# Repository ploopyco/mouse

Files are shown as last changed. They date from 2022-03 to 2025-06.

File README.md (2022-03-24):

# The Ploopy Mouse

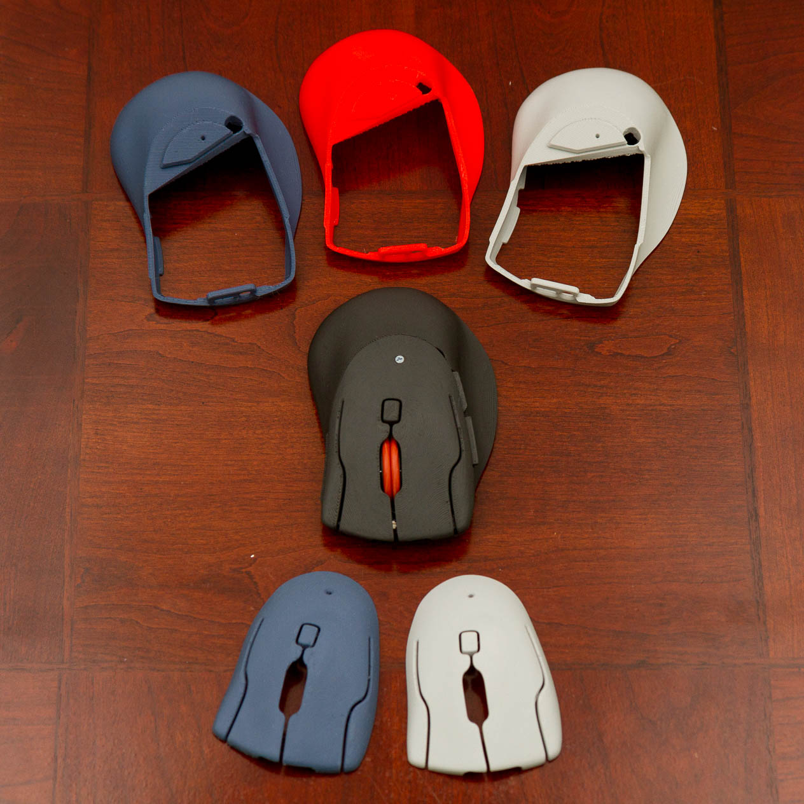
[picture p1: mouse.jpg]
The Ploopy Mouse


By some stroke of luck, you've made your way here. The Ploopy Mouse. Your life will never be the same.

This repository contains all of the design and production files necessary to make a Ploopy Mouse. We've also included some kick-ass documentation in the Wiki on how to get it made, assemble it, and program it.

What are you waiting for? Your new life awaits.

## QMK?!

Kits bought from the [Ploopy store](https://ploopy.co/product-category/mouse/) come with QMK preloaded. Check out the Wiki for instructions on how to load new firmware onto your device. (It's super easy!)

The firmware hex file that ships with all Mice is included in this repository as well, as `ploopyco_mouse_via.hex`. The hex was built with QMK version 0.11.1.

## Under what license is this released?

Everything in this repository is released under OHL CERN v2-S. Check the LICENSE.md file for full license text.

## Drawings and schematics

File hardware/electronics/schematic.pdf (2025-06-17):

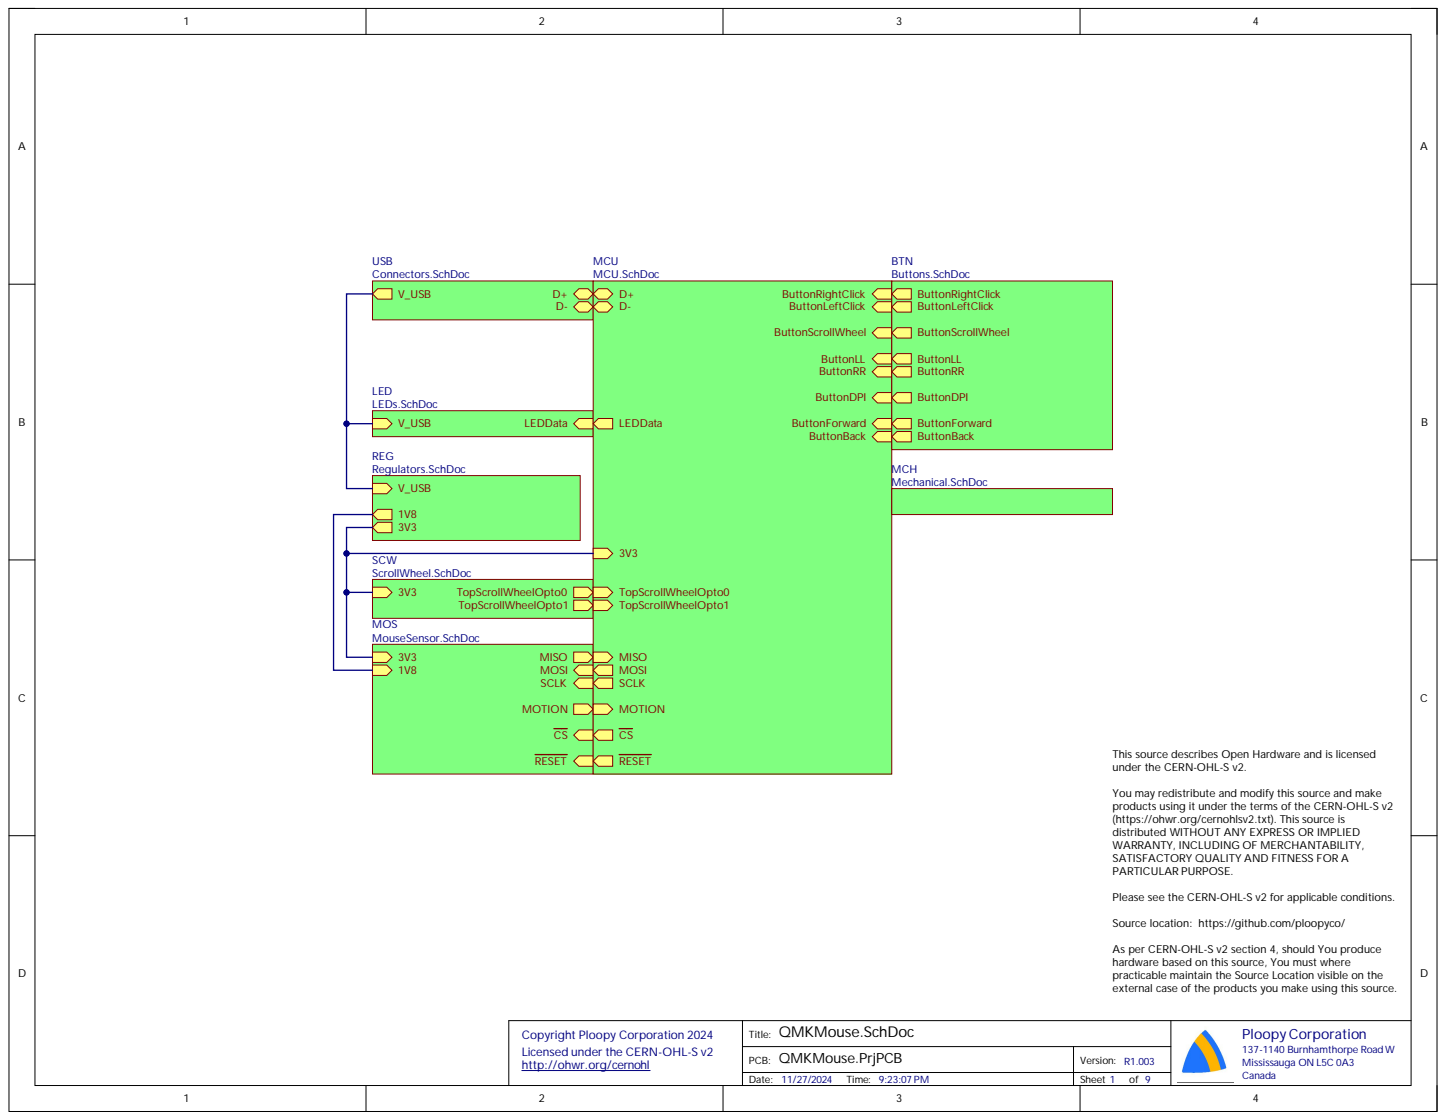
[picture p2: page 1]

This source describes Open Hardware and is licensed
under the CERN-OHL-S v2.

You may redistribute and modify this source and make
products using it under the terms of the CERN-OHL-S v2
(https://ohwr.org/cernohlsv2.txt). This source is
distributed WITHOUT ANY EXPRESS OR IMPLIED
WARRANTY, INCLUDING OF MERCHANTABILITY,
SATISFACTORY QUALITY AND FITNESS FOR A
PARTICULAR PURPOSE.

Please see the CERN-OHL-S v2 for applicable conditions.

Source location: https://github.com/ploopyco/

As per CERN-OHL-S v2 section 4, should You produce
hardware based on this source, You must where
practicable maintain the Source Location visible on the
external case of the products you make using this source.

Copyright Ploopy Corporation 2024
Licensed under the CERN-OHL-S v2
http://ohwr.org/cernohl

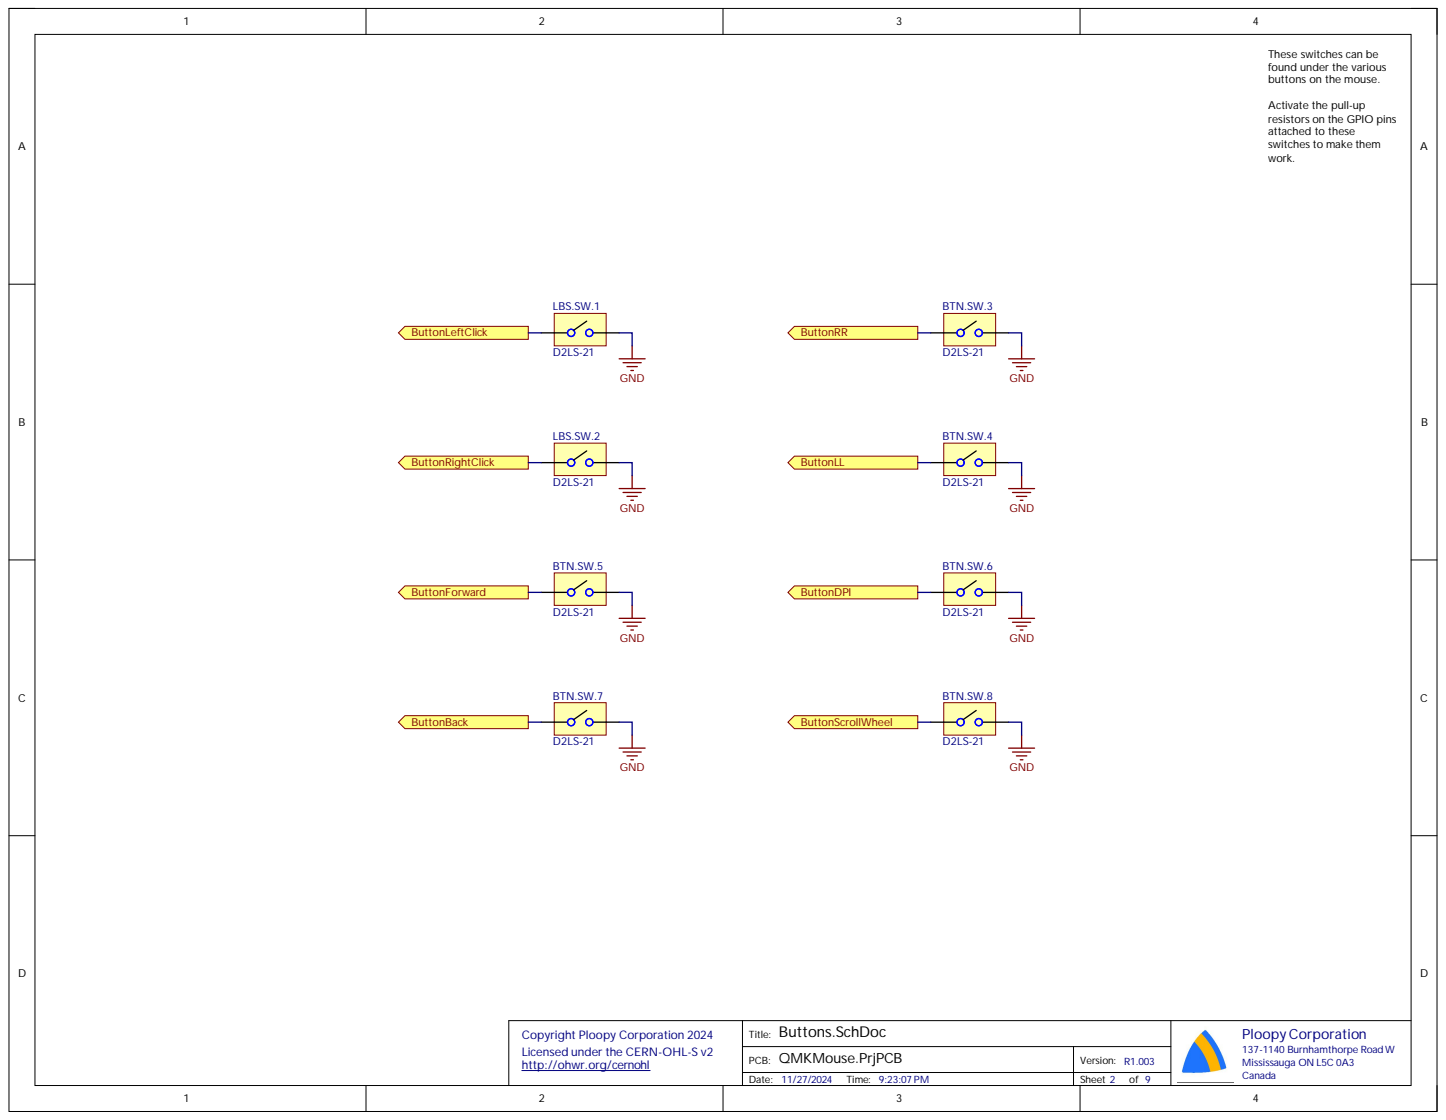
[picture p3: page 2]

These switches can be
found under the various
buttons on the mouse.

Activate the pull-up
resistors on the GPIO pins
attached to these
switches to make them
work.

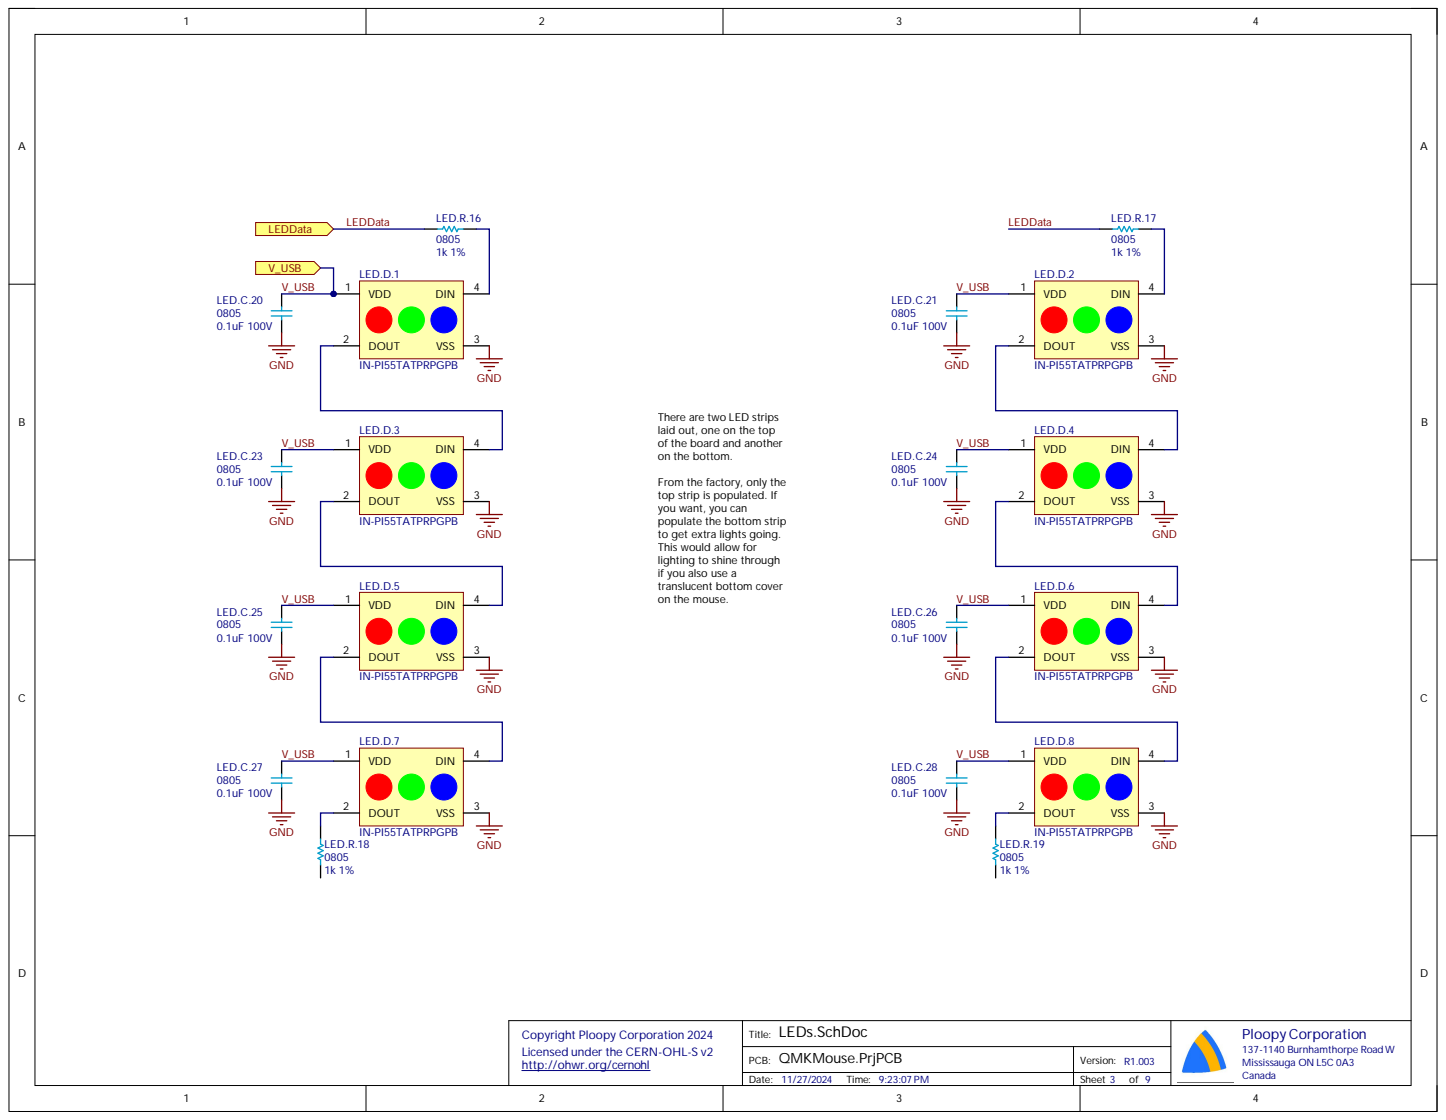
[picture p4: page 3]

There are two LED strips
laid out, one on the top
of the board and another
on the bottom.

From the factory, only the
top strip is populated. If
you want, you can
populate the bottom strip
to get extra lights going.
This would allow for
lighting to shine through
if you also use a
translucent bottom cover
on the mouse.

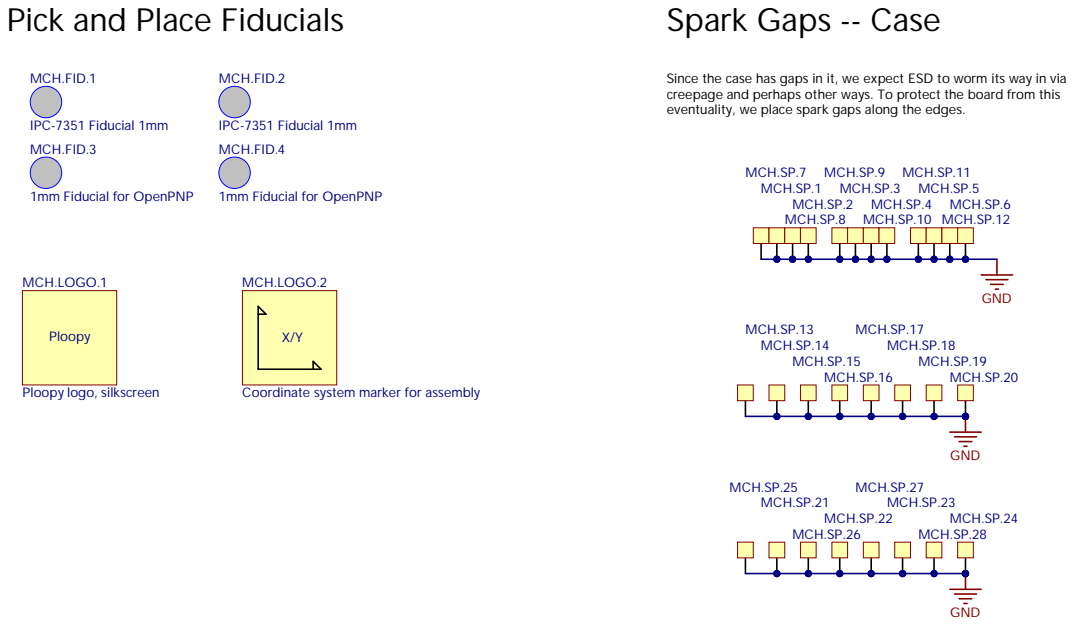
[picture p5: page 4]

Pick and Place Fiducials

Spark Gaps -- Case MCH.SP.7 MCH.SP.1 MCH.SP.8 MCH.SP.2 MCH.SP.9 MCH.SP.3 MCH.SP.10 MCH.SP.4 MCH.SP.1

Since the case has gap
creepage and perhap
eventuality, we place s

s other ways. To protect the board from this
park gap

pect ESD to worm its way in via

Coordinate system marker for assem

Cop
Licensed under the CE
http

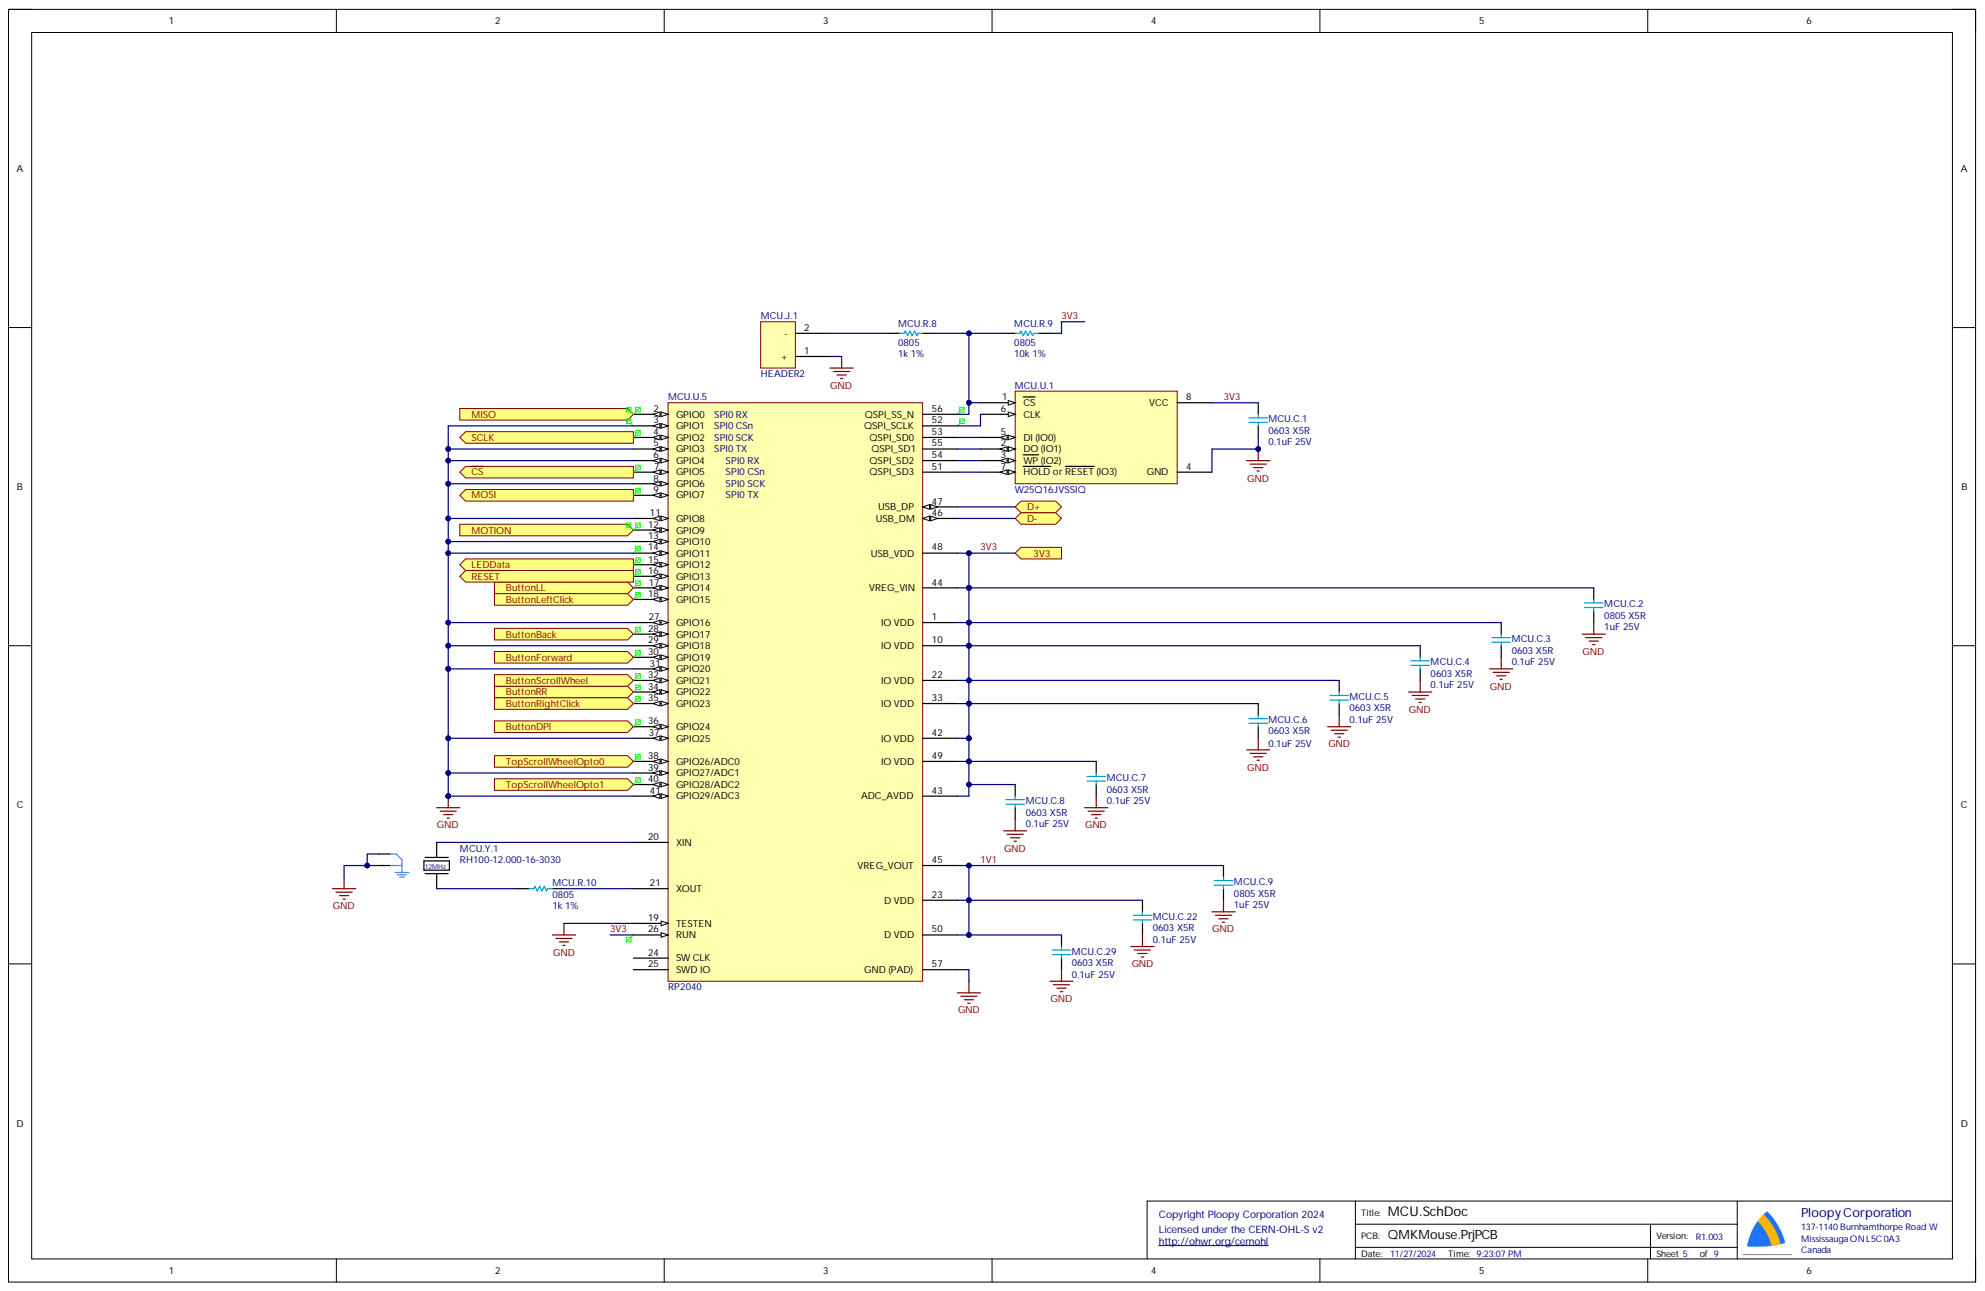
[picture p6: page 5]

SCLK MISO MOTI 6 | 3

M 9 | W25Q16J VSSI Q D-

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

PC B : QMKMo u se.P rj PC B | V e rsion : R 1 . 003

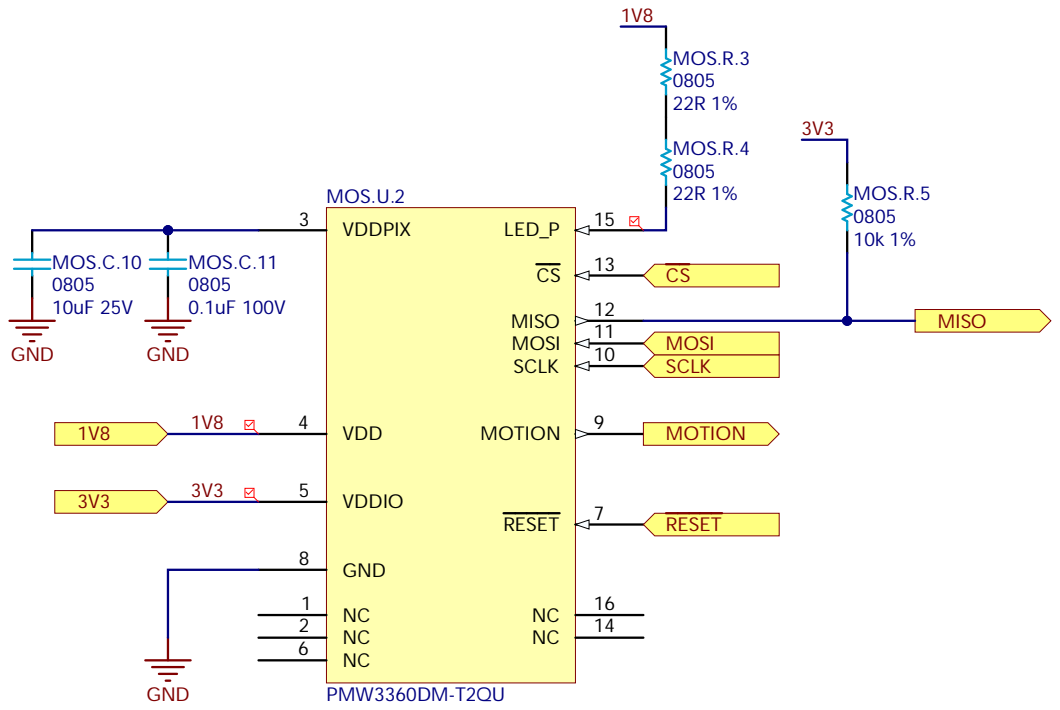
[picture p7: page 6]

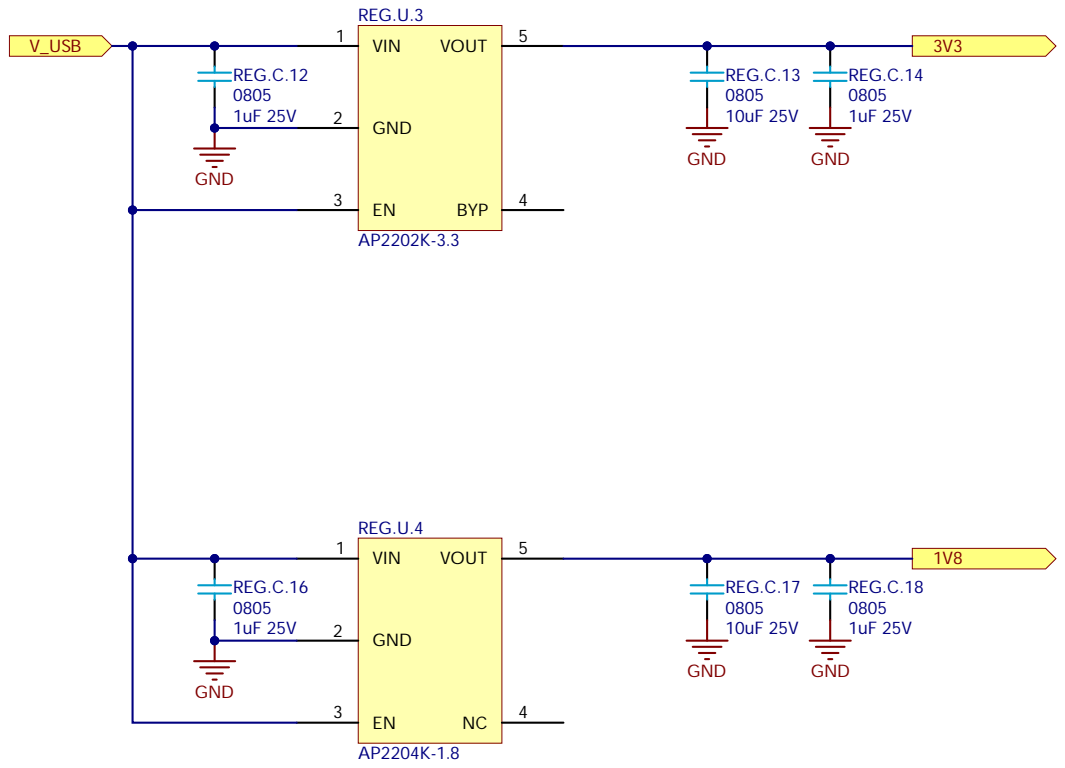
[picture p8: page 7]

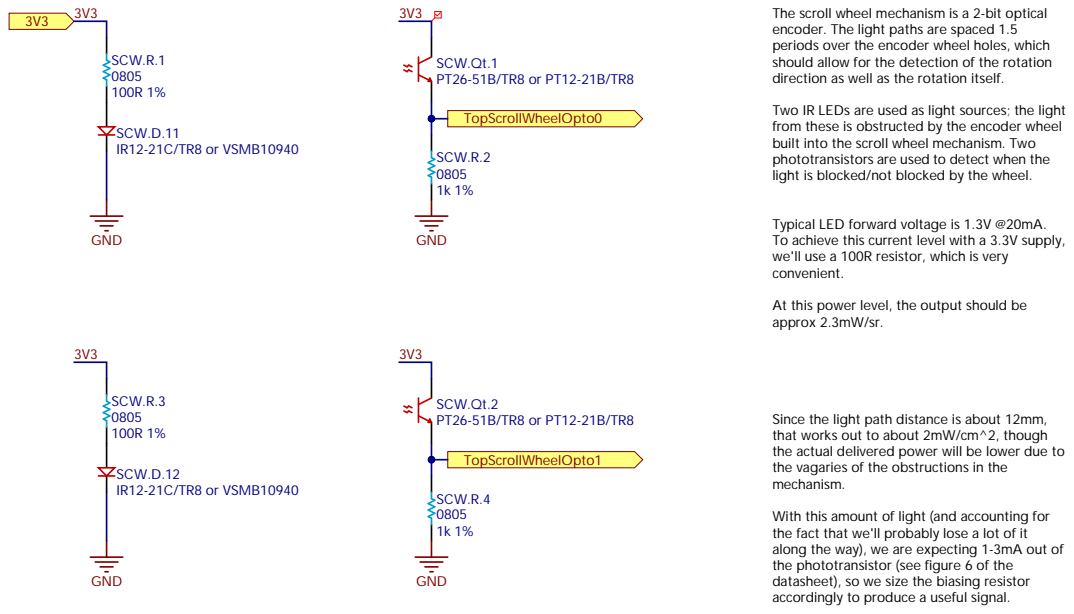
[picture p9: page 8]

The scroll wheel mechanis
encoder. The light paths are s
period
should allow for the detection of the rotation direction as well as the rotation itself. Two IR LEDs are used as light sources; the light
TopScrollWheelOpto0 TopScrollWheelOpto1

s over the encoder wheel holes, which

from these is ob
built into the scroll wheel mechanis
phototransistors are used to
light is blocked/not blocked by the wheel. Typical LED forward voltage is 1.3V @20m

structed by the encoder wheel

To achieve this current level with a 3.3V sup
we'll use a 100R resistor, which is very
convenient. At this power level, the output should be

Since the light path distance is about 12m
that work
the actual delivered power will be lower due to
the vagaries of the ob
mechanis

s out to about 2mW/cm

With this amount of light (and accounting for
the fact that we'll probably lose a lot of it
along the way), we are ex
the phototransistor (see figure 6 of the datasheet), so we size the biasing resistor

accordingly to produce a useful signal.

Cop
Licensed under the CE
http

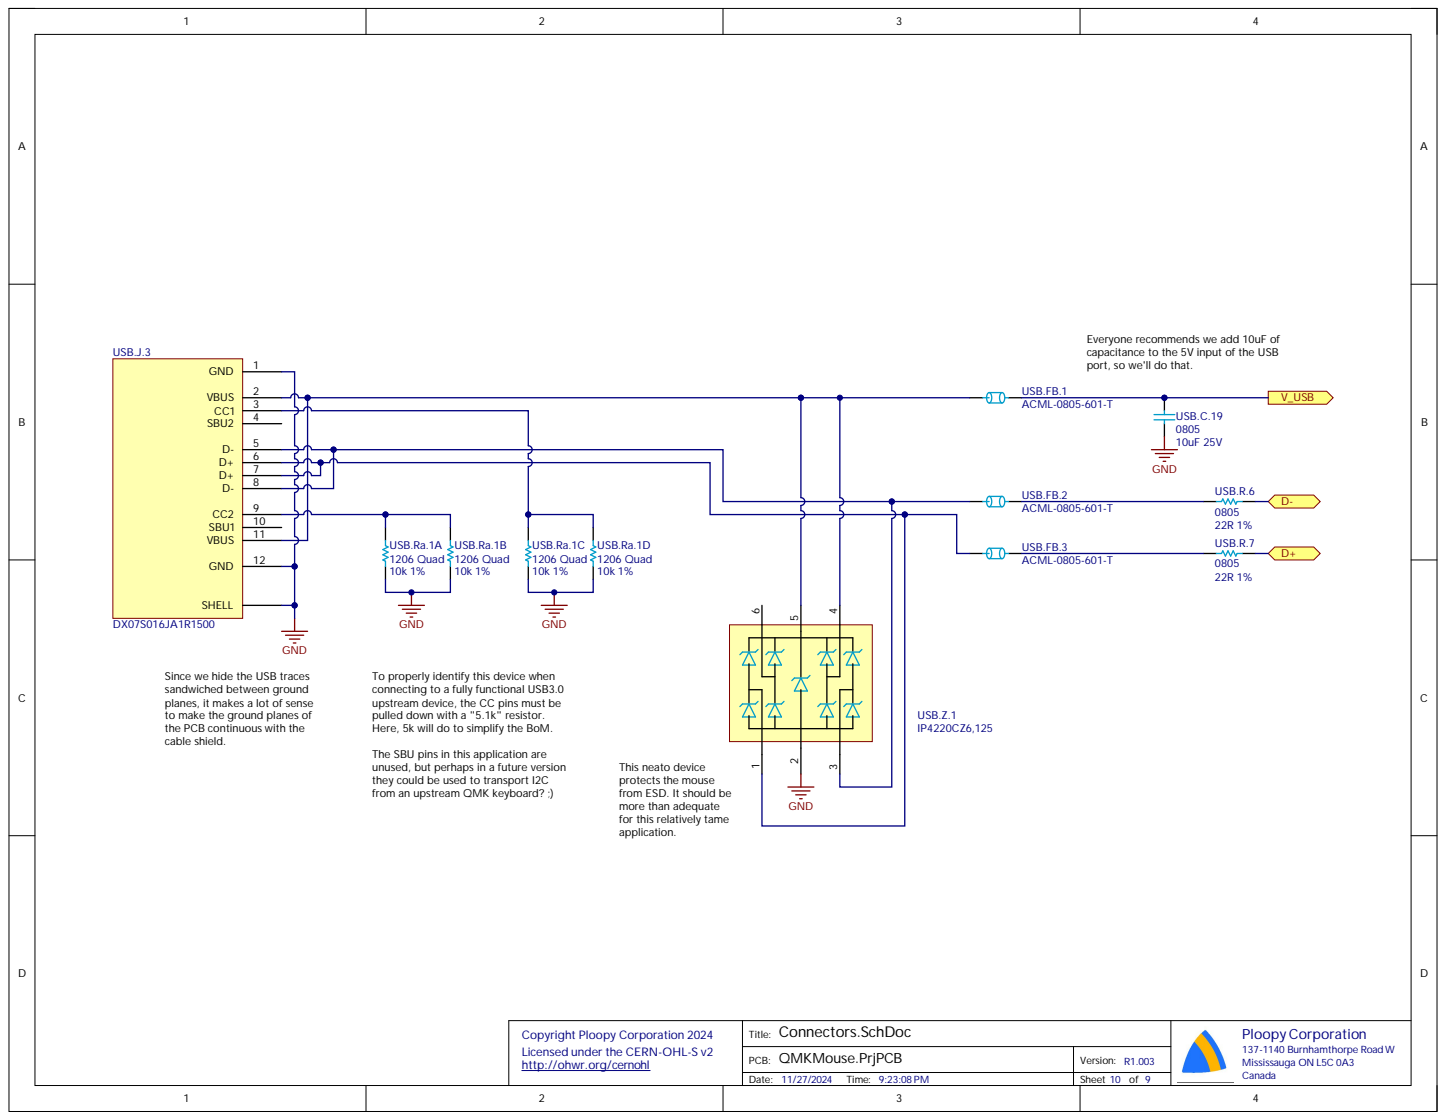
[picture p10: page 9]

Everyone recom
capacitance to the 5V input of the USB port, so we'll do that.

Since we hide the USB traces sandwiched between ground planes, it makes a lot of sense

To properly identify this device when
connecting to a fully functional USB3.0
pulled down with a "5.1k" resistor.
Here, 5k will do to sim

to make the ground planes of
the PC
cable shield

The SB
unused, but perhap
they could be used to trans
from an up

U pins in this ap

This neato device protects the mouse

from ESD. It should be more than adequate

for this relatively tame

Cop
Licensed under the CE
http

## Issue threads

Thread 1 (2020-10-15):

Wiki & files are missing

KGOH, 2020-10-15:
Hello. I've just received hardware to assembly a ploopy by myself and found out that the project wiki is missing. Where can I find wiki now?

KGOH, 2020-10-15:
Ah. They're moved to https://github.com/ploopyco/trackball/

Closed 2020-10-15.

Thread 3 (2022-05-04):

KiCad

bigtree908, 2022-05-04:
Could the Schematics be posted in a KiCad compatible format?

keyboard-magpie, 2022-05-05:
It's designed in altium so transferring it across is not trivial. You can create an altium account and use their online viewer for free to view schema/pcb files and even create gerbers.

Riesi, 2023-01-19:
Not sure if anyone has notifications enabled for this issue still.

But I ported the Altium files to KiCAD. Be aware that I haven't verified the correctness of the design as described in the README disclaimer! I only made the DRC happy and made sure the 3D view is correct for now.
https://github.com/Riesi/ploopy_mouse_kicad

Riesi, 2023-01-19:
Ok I already found a difference at the optical sensor :sweat_smile:
I hope I can get the Gerber diff working soon!

Closed 2022-05-21.

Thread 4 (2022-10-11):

Choice of more standard-sized switches

silverhook, 2022-10-11:
I really like the concept of both the Ploopy mouse and trackball.

But especially since it’s OSHW, I’d probably like to modify it to my liking.

One of the things that I noticed with my mice is that I prefer other switches for the buttons (and wheel encoders). And I was surprised that Ploopy uses a different size switches than all the mice I’ve had so far.

Would it be possible to easily replace the switches (and encoder) with more standard format ones?

(e.g. here’s a pretty good guide for [different switches](https://mouseclub.co/pages/mouse-switch-guide) and another one for [different encoders](https://mouseclub.co/pages/encoder-guide))

ploopyco, 2024-04-08:
The D2LS switch is quite common, and is arguably easier to replace than its thru-hole cousins. That said, we'd be happy to look at contributions in the form of a PR. :)

Closed 2024-04-08.

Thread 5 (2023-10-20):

Bad link in Wiki to Schematic

mrlinuxfish, 2023-10-20:
[The PCB Wiki page](https://github.com/ploopyco/mouse/wiki/Appendix-A%3A-Printed-circuit-boards) has two links which point to a nonexistent Main branch instead of the Master branch. (both are links to the schematics).

Easiest solutions I see are:
- Renaming Master branch to Main
- Reformat the link to go to Master

I also decided to check all the other links in the wiki and noticed about half of the QMK links go to the beta docs and the other half to the main docs. In the past, the beta docs were identical, but better formatted, however, a while ago I had problems with the beta docs being out of date in relation to the main docs.

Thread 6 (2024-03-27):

Hardware Update?

pyrotelekinetic, 2024-03-27:
It seems like the mechanical hardware files here don't match what I got in the pre-assembled ploopy mouse I purchased from [ploopy.co](https://ploopy.co/mouse) around August of 2021.

Could the files here be updated? Ideally each revision would be available, at least as a git tag.

Thanks, can't wait to print a replacement part so I can get back to using my favorite mouse!

ploopyco, 2024-04-08:
Please send us an email at contact@ploopy.co and we'll get you sorted out. The original mouse design (which I think you have one of) wasn't open source, and was later replaced with one that's much easier to assemble/print.

Closed 2024-04-08.

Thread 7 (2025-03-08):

Supply Gerber files or suggest alternate way for getting them

GhostDog98, 2025-03-08:
I'm aware that there's been an issue surrounding kicad imports (https://github.com/ploopyco/mouse/issues/3), and that's fair enough since you've got your preferences for design software.
However, it isn't really reasonable to expect someone to buy a multi-thousand dollar subscription to be able to export the gerbers.

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

Is there an alternate way to get the gerbers without this subscription?

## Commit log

2022-03-24 public release of electronics and mechanical files
    [Buttons.SchDoc, Cage.STL, Chip_Passives.PcbLib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]
2025-04-24 updated mechanical files
    [Cage.STL, RightButtons.STL, ScrollWheel.stl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]
2025-06-17 updated electronics files to r1.003
    [Buttons.SchDoc, Chip_Passives.PcbLib, Chip_Passives.SchLib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]
